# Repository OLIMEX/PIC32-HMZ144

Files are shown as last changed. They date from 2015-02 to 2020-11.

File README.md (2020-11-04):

# PIC32-HMZ144 development board

Product web-page:

https://www.olimex.com/Products/PIC/Development/PIC32-HMZ144/open-source-hardware

Latest revision features:

* Completely OSHW (Open-Source HardWare)
* PIC32MZ2048EFM144 512KB RAM 2MB Flash (other versions of the chip were used for older revisions)
* USB-OTG connector
* MicroSD card connector
* Standard ICSP for debugging and programming
* JTAG pins exposed on 0.1" step 6 pins
* EXT1 and EXT2 50 pin 0.1" connectors for all PIC ports
* RESET and USER buttons
* PWR and STATUS LEDs
* LiPo battery charger and connector
* UEXT connector
* Dimensions: 77 x 52 mm

Demo-software can be found in the software section of the board's web-page. 

Hardware revsion note:

A small number of initially distributed boards might beed a hardware patch for better operation. If your board is revision B and has Q1 with value of 24MHz make sure to apply all of the revision C changes listed below (1, 2, and 3) manually. These hardware changes are required ONLY for boards with printed board revision B and crystal Q1=24Mhz. If your board has a printed revision C or newer, or if Q1=12MHz no hardware changes are required!  

Hardware revisions:

* Revision B patch and revision C notes:

1. The crystal Q1 was changed from 24MHz to Q12.000MHz/HC-49S/SMD/20pF/30ppm;
2. Crystal capacitors (C29, C32) were changed from 27pF to 20pF as required in the errata: "C2=Cload, C1=Cload-2pF" and to have some pF spare, because during production, the capacitance is increased due to flux or dirt;
3. R36=10k pull-up to 3.3V was added to the OSCO pin, i.e. MCU pin<72>.

* Revision C1:

  This is the patched version of PIC32-HMZ144_Rev_C with soldered PIC32MZ2048EFG144-I/PH processors instead of PIC32MZ2048ECG144-I/PH

1. The main processor was changed from PIC32MZ2048ECG144-I/PH to PIC32MZ2048EFG144-I/PH (the ECG was declared "not recommended for new designs" by Microchip)
2. R36 was changed from 10k to 1.5k;
3. Removed quartz Q1. Q1, C29, C32 and R30 were changed to NA - this is because of the errata sheets of both chips. Refer to 4;
4. Added oscillator CD1 instead. CD1 is 24MHz oscillator;
5. Q2, C30 and C31 were changed to NA.

* Revision C2:

  Only difference compared to C1 is a typo in the schematic values, R36 should be marked as 150 Ohm resistor. 
  
  No boards with R36 = 1.5k were ever produced.

* Revision D:

1. The PIC was changed from PIC32MZ2048ECG144T-I/PH to PIC32MZ2048EFM144T-I/PH 
2. According to the PIC32MZ2048 errata sheets:

- Primary oscillator crystal, revision A3 silicon: the primary oscillator has been tested in a normal power-up sequence and supports specific crystal operation.
- The secondary oscillator (SOSC) does not support crystal operation.

Because of this we have added 2 oscillators and have changed the 2 crystals with all corresponding components to NA.

3. One resistor added in series to the 24MHz's crystal. Check the errata sheet for PIC32MZ2048EFM144-I/PH silicon revision A3.
4. PWR_LED and LED1 packages changed.
5. The open source hardware logo was added to the bottom silkscreen.
6. U4 changed from SY8009AAAC(SOT23-5) to SY8089AAAC(SOT23-5).
7. L3 changed from CL470nH/0805/1.76R/250mA to FB0805/600R/2A.
8. FET1 changed from IRLML6402 to WPM2015-3/TR(SOT23-3).
9. Few spacing improvements:
	9.1. The USB-OTG's connector moved 1.00mm towards the middle of the board;
	9.2. The MICRO-SD card's package changed from TFC-WPAPR-08 to TFC-9P-1.5H(ATFFS150A01BR016);
10. UEXT's and Q2's packages improved.

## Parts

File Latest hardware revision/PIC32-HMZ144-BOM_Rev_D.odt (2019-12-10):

PIC32-HMZ144_Rev_D

18.11.2019

Qty Value Device Parts

2 0R(Board_Mounted) R0603 R10, R12

1 0R/R0603 R0603 R37

1 1.1k/1% R0603 R33

1 1M/1% R0603 R9

1 1N5819(S4SOD-123) SOD-123 D1

2 1N5819(SS14) SS14 D2, D3

3 1k R0603 R3, R22, R27

2 2.2k R0603 R13, R15

1 2.2uH/1.5A/DCR<0.1R/CD32 CD32 L4

1 3M R0603 R8

1 4.99k/1% R0603 R32

4 10k R0603 R4, R21, R24, R25

2 10nF C0603 C8, C15

5 10uF/6.3V C0603 C7, C13, C16, C17, C25

1 13k/1% R0603 R6

1 15k R0603 R11

9 22uF/6.3V C0603 C1, C2, C3, C4, C6, C12, C14, C33, C34

2 20pF C0603 C29, C32

1 27pF C0603 C37

3 47k R0603 R2, R14, R16

3 100k R0603 R5, R7, R23

16 100nF C0603 C5, C9, C10, C11, C18, C19, C20, C21, C22, C23, C24, C26, C27, C28, C35, C38

4 330R R0603 R1, R26, R28, R29

1 DW02R DW02R 3.7V-LI_BAT

4 FB0805/600R/2A L0805 FB1, L1, L2, L3

1 GBH-254-SMT-10 GBH-254-SMT-10 UEXT

1 32.768KHZ/20ppm/3.3V/3.20X2.50X1.00MM KK3270046 CD2

1 LED/GREEN/0603 LED-0603 LED1

1 LED/RED/0603 LED-0603 PWR_LED

1 MCP73812T-420I/OT SOT-23-5 U2

2 NA FE25-2FEMALE EXT1, EXT2

7 NA R0603 R17, R18, R19, R20, R31, R34, R35

1 NA(F535L-24(24MHz/50ppm/3.3V/5.00x3.20mm)) 5032_4P CD1

1 NA(1M/1%) R0603 R30

1 NA(10k) R0603 R36

2 NA(10pF) C0603 C30, C31

1 NA(100nF) C0603 C36, C39

1 NA(AP431SA) SOT23 SR1

1 NA(HN1X6) HN1X6 JTAG

1 NA(MC-306_32.768KHz/6pF) MC-306 Q2

1 Q24MHz/HC-49S/SMD/20pF/20ppm HC-49S Q1

1 PIC32MZ2048EFG144-I/PH PIC32MZ2048ECG144-I/PH U1

1 RA1206_(4X0603)-100k R_MATRIX_4E RM1

1 SY6280 SY6280 U3

1 SY8089AAAC(SOT23-5) SY8008 U4

2 T1107A(6X3,8X2,5MM) 6X3,8X2,5MM BUT, RST

1 TESTPAD3 TESTPAD3 GND_PIN

1 TFC-9P-1.7H(ATFFS150A01BR016) TFC-9P-1.7H MICRO-SD

1 USB-OTG MINI_USB9 USB

1 WF6S WF6S ICSP

1 WPM2015-3/TR(SOT23-3) SOT23-3 FET1

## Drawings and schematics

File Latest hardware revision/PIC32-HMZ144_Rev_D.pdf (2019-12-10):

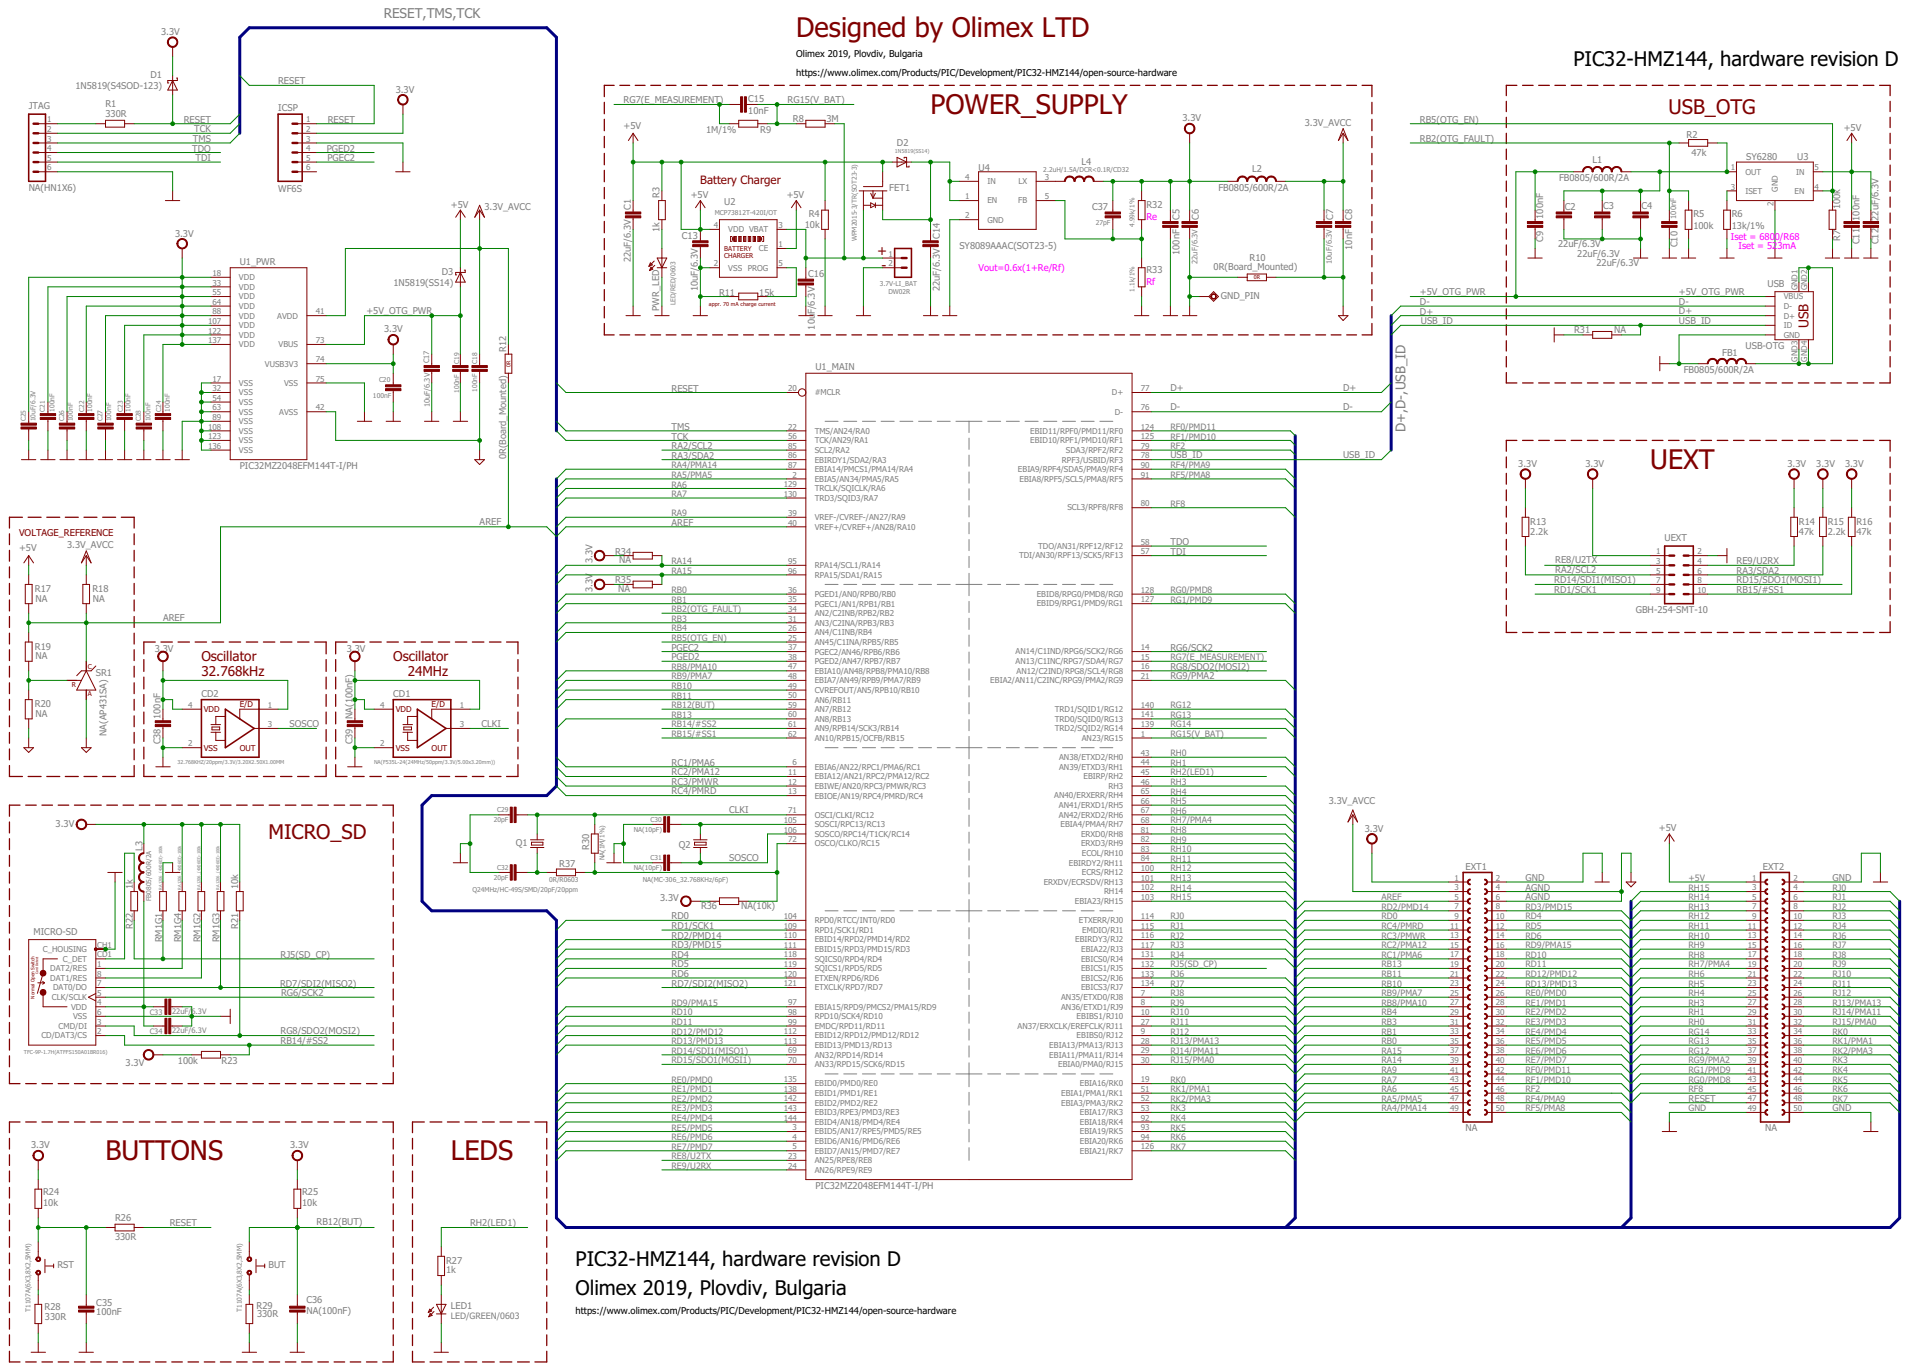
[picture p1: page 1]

Designed by Olimex LTD

https://www.olimex.com/Products/PIC/Development/PIC32-HMZ144/open-source-hardware

3 TMS | 3
TDO 4 | PGED2 4
5 TDI | 5 PGEC2

Iset = 523mA ReRf Vout=0.6x(1+Re/Rf)

appr. 70 mA charge current

122
137

17 | | 73 VUSB3V3

6 AGND | 5
10 | 9 | 10
12 | 11 | 12

22 | RH6 21 | RK0 RJ15/PMA0 RJ15/PMA0 RJ14/PMA11 RJ14/PMA11 RJ13/PMA13 RJ13/PMA13 RJ12 RJ12 RJ11 RJ11 RJ10 RJ10 RJ9 RJ9 RJ8 RJ8 RJ7 RJ7 RJ6 RJ6 RJ4 RJ4 22

RF1/PMD10 | RG0/PMD8 43 | RK4 RK3 44
RF2 | RF8 45 | RK5 RK4 46

RF4/PMA9 | RESET 47 | 48
RF5/PMA8 | GND 49 | 50 GND

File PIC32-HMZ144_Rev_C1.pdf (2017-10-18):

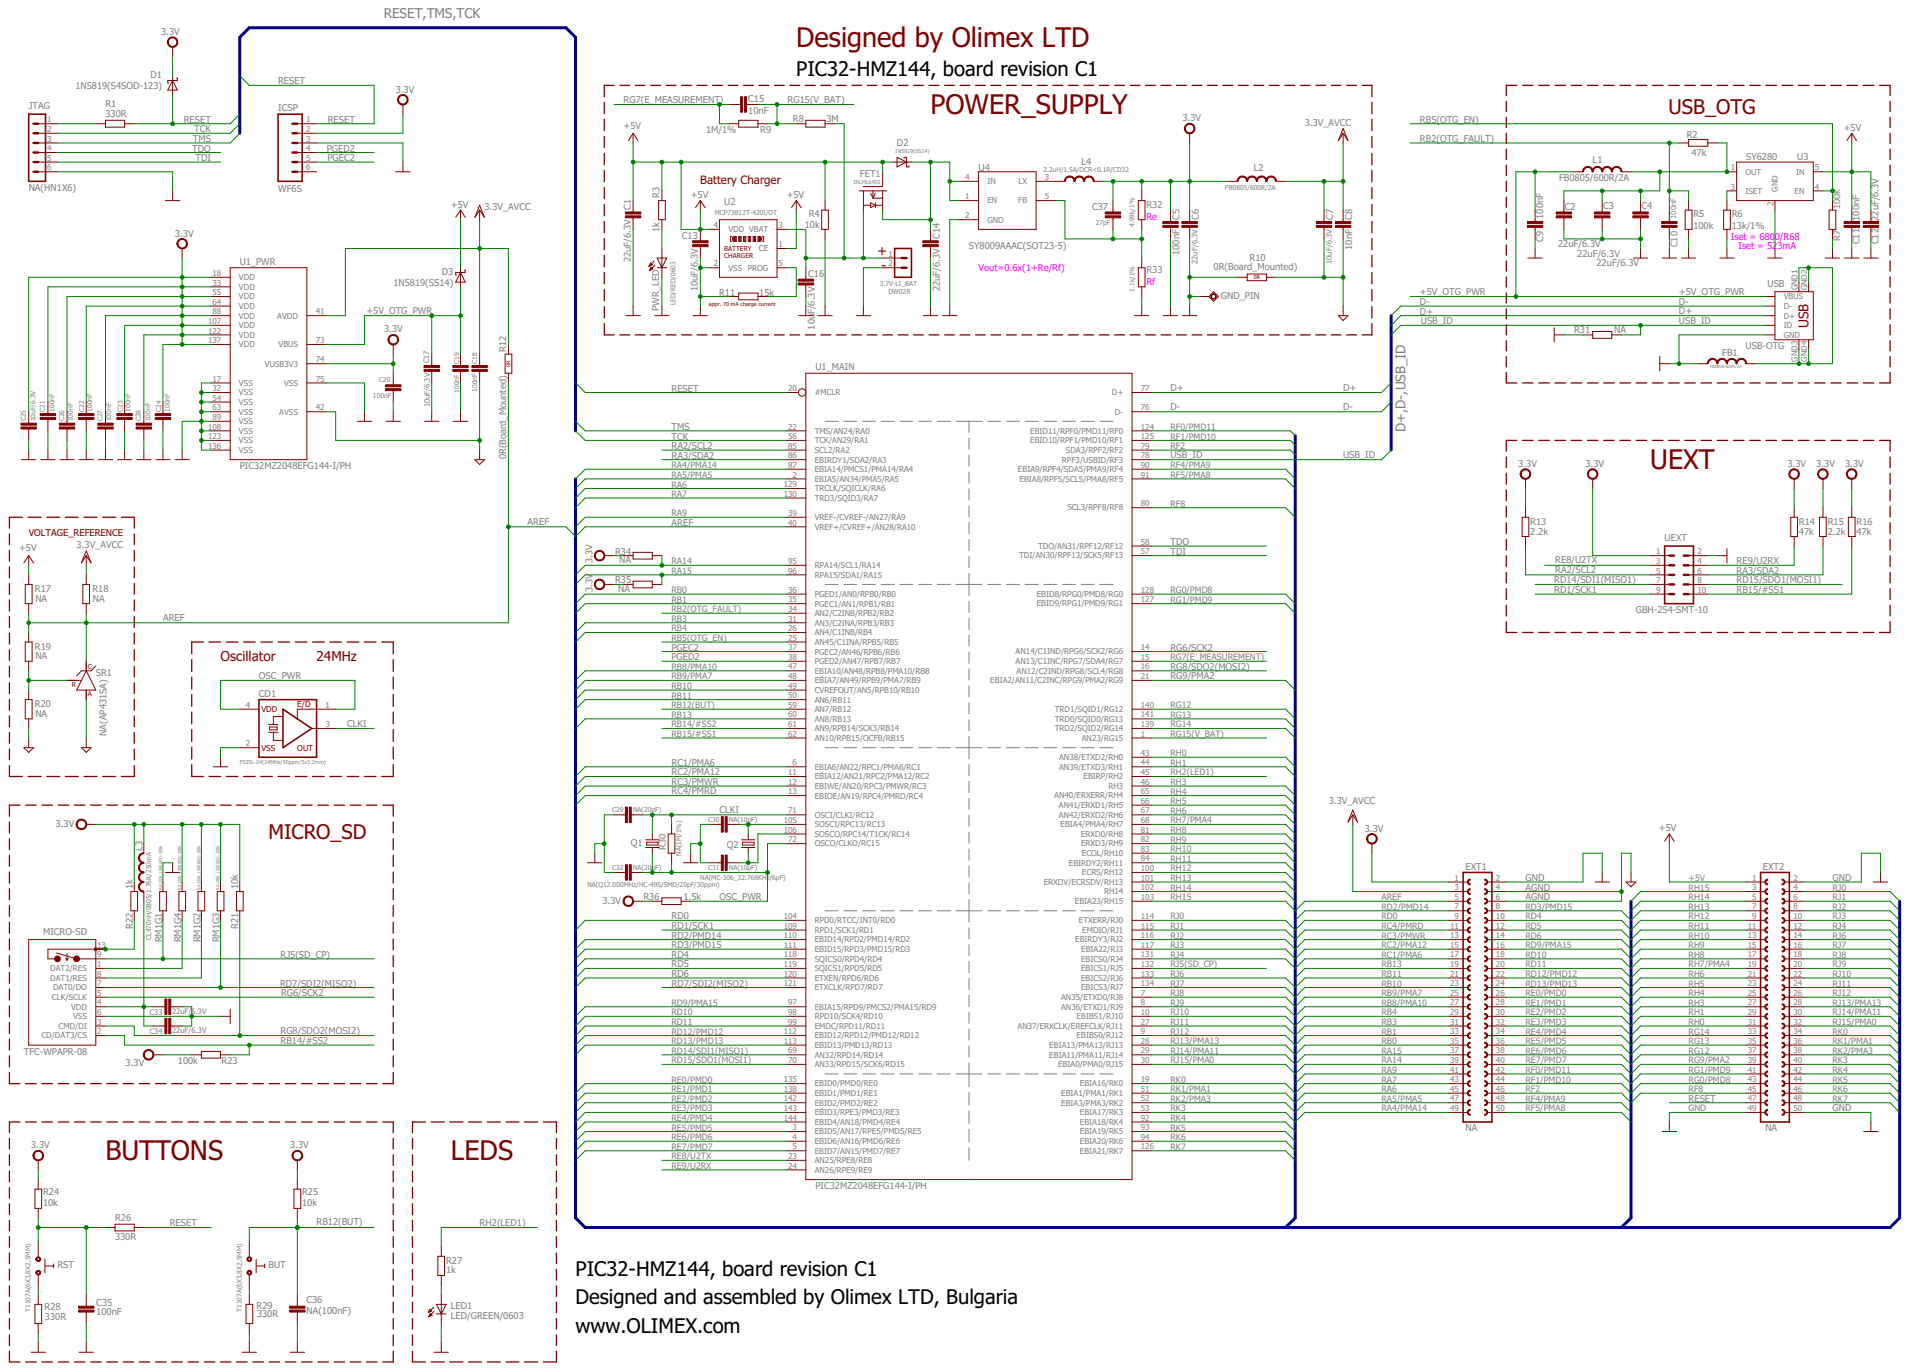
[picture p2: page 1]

Designed by Olimex LTD

3 TMS | 3
TDO 4 | PGED2 4
5 TDI | 5 PGEC2

Iset = 523mA ReRf Vout=0.6x(1+Re/Rf)

appr. 70 mA charge current

10 | 9 | 10
12 | 11 | 12

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

RF4/PMA9 | RESET 47 | 48
RF5/PMA8 | GND 49 | 50 GND

PIC32-HMZ144, board revision C1
Designed and assembled by Olimex LTD, Bulgaria
www.OLIMEX.com

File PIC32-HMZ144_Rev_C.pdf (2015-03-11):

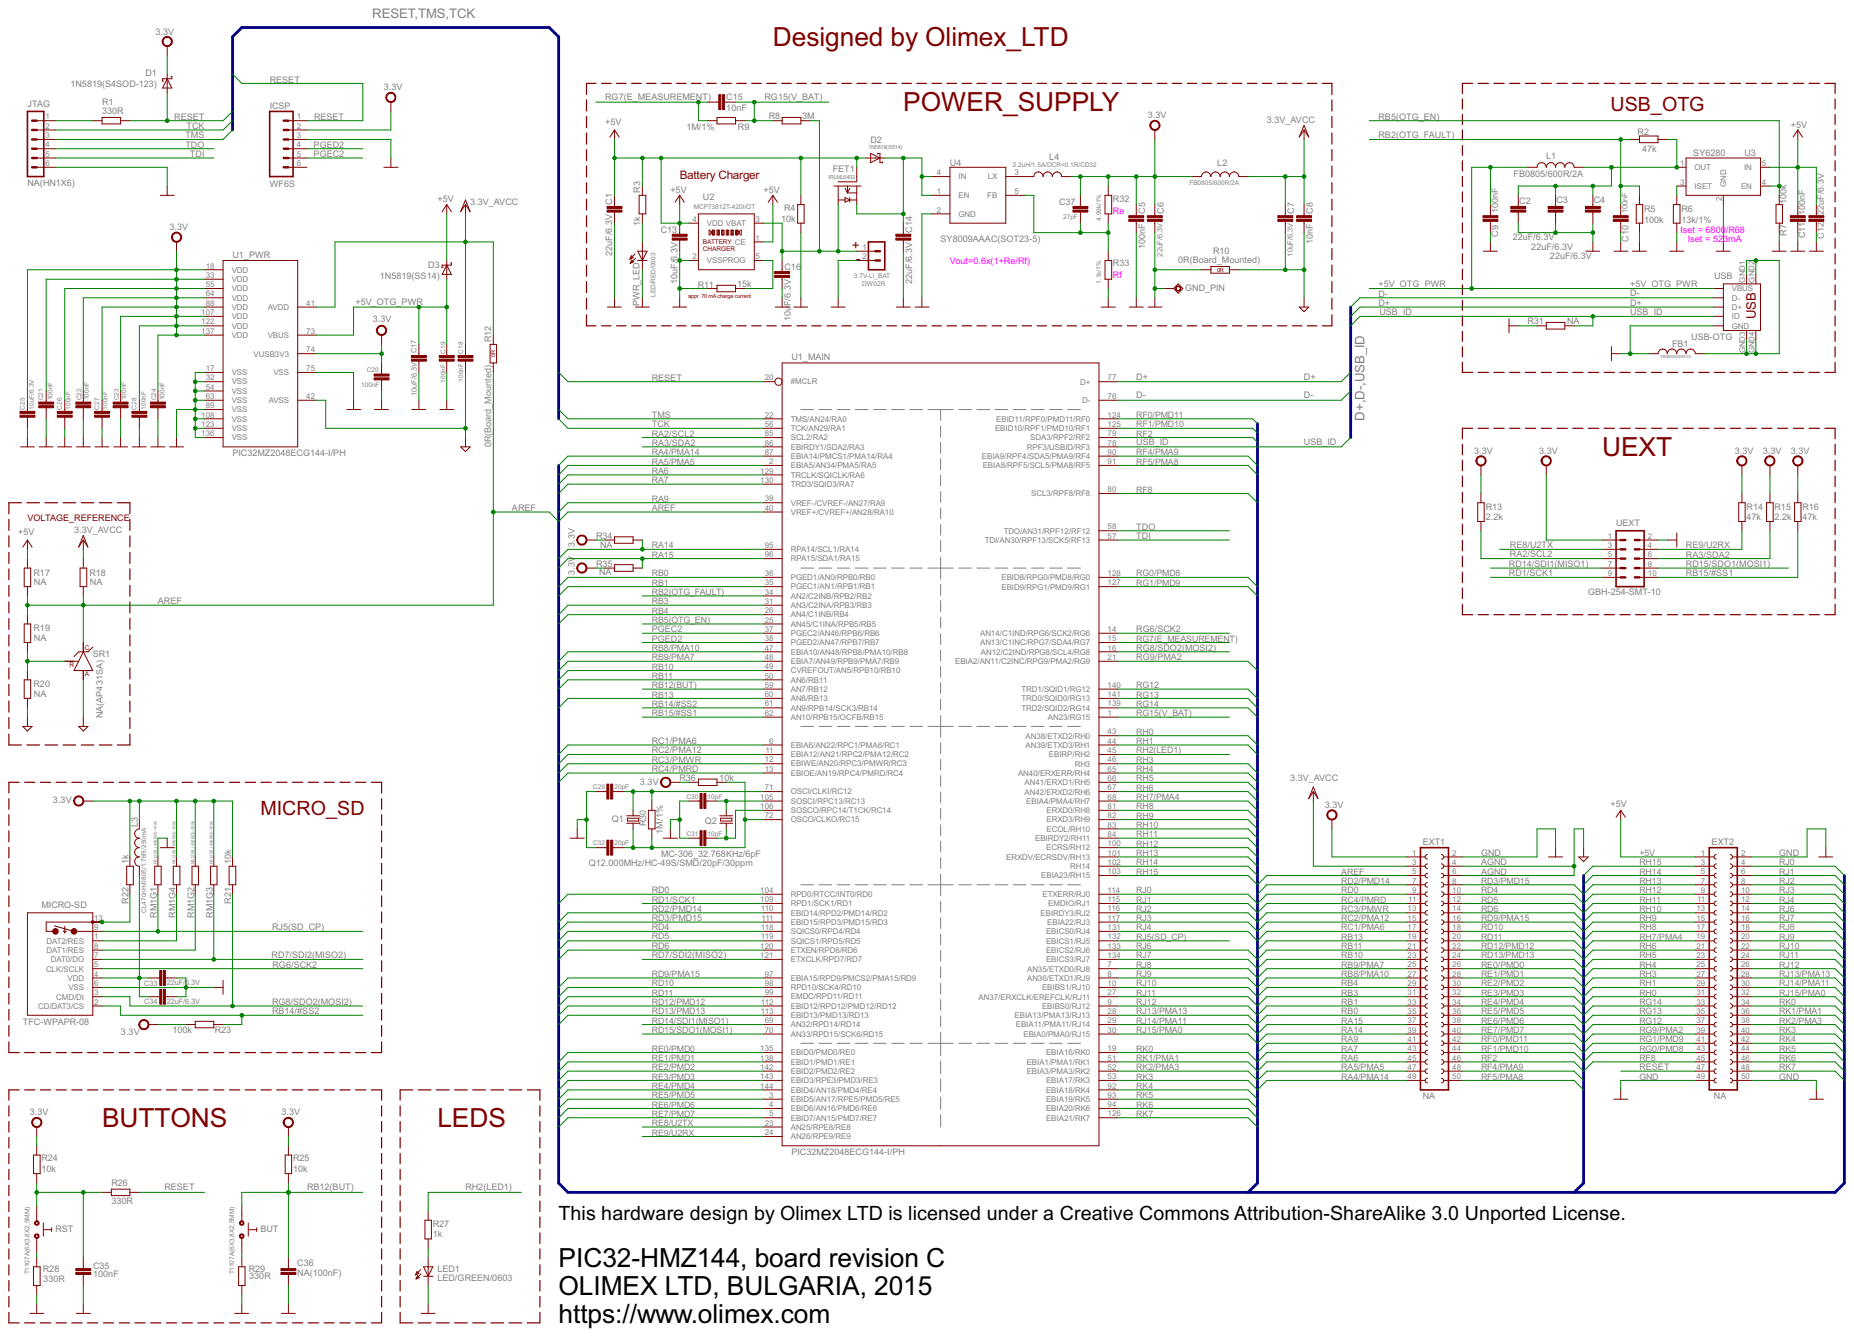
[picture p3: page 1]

4 TDO | 4 PGED2
5 TDI | 5 PGEC2

Iset = 523mA ReRf Vout=0.6x(1+Re/Rf)

appr. 70 mA charge current

137 17 | 73 VUSB3V3

3 AREF 5 | 4 AGND | 3

RD1/SCK1 | | RC4/PMRD 11 | 12 | 11 | 12

111 | | RC3/PMWR 13 RC2/PMA12 15 | 14 16 | RH5 RH10 13 RH9 15 | RJ3 RJ3 14 16

9 | 10 | 9 | 10

RB4 29 | 30 RE2/PMD2 | RH1 29 | 30

RA15 37 | 38 RE6/PMD6 | RG12 37 | 38

RE1/PMD1 138 | | RA6 45 | RF2 46 | RF8 45 | 46
RE2/PMD2 RE3/PMD3 | | RA5/PMA5 47 RA4/PMA14 49 | 48 RF4/PMA9 50 RF5/PMA8 | RESET 47 GND 49 | 48 50 GND

RA7 43 | 44 RF1/PMD10 | RG0/PMD8 43 | 44

RE5/PMD5 | NA | NA

This hardware design by Olimex LTD is licensed under a Creative Commons Attribution-ShareAlike 3.0 Unported License.
PIC32-HMZ144, board revision C
OLIMEX LTD, BULGARIA, 2015
https://www.olimex.com

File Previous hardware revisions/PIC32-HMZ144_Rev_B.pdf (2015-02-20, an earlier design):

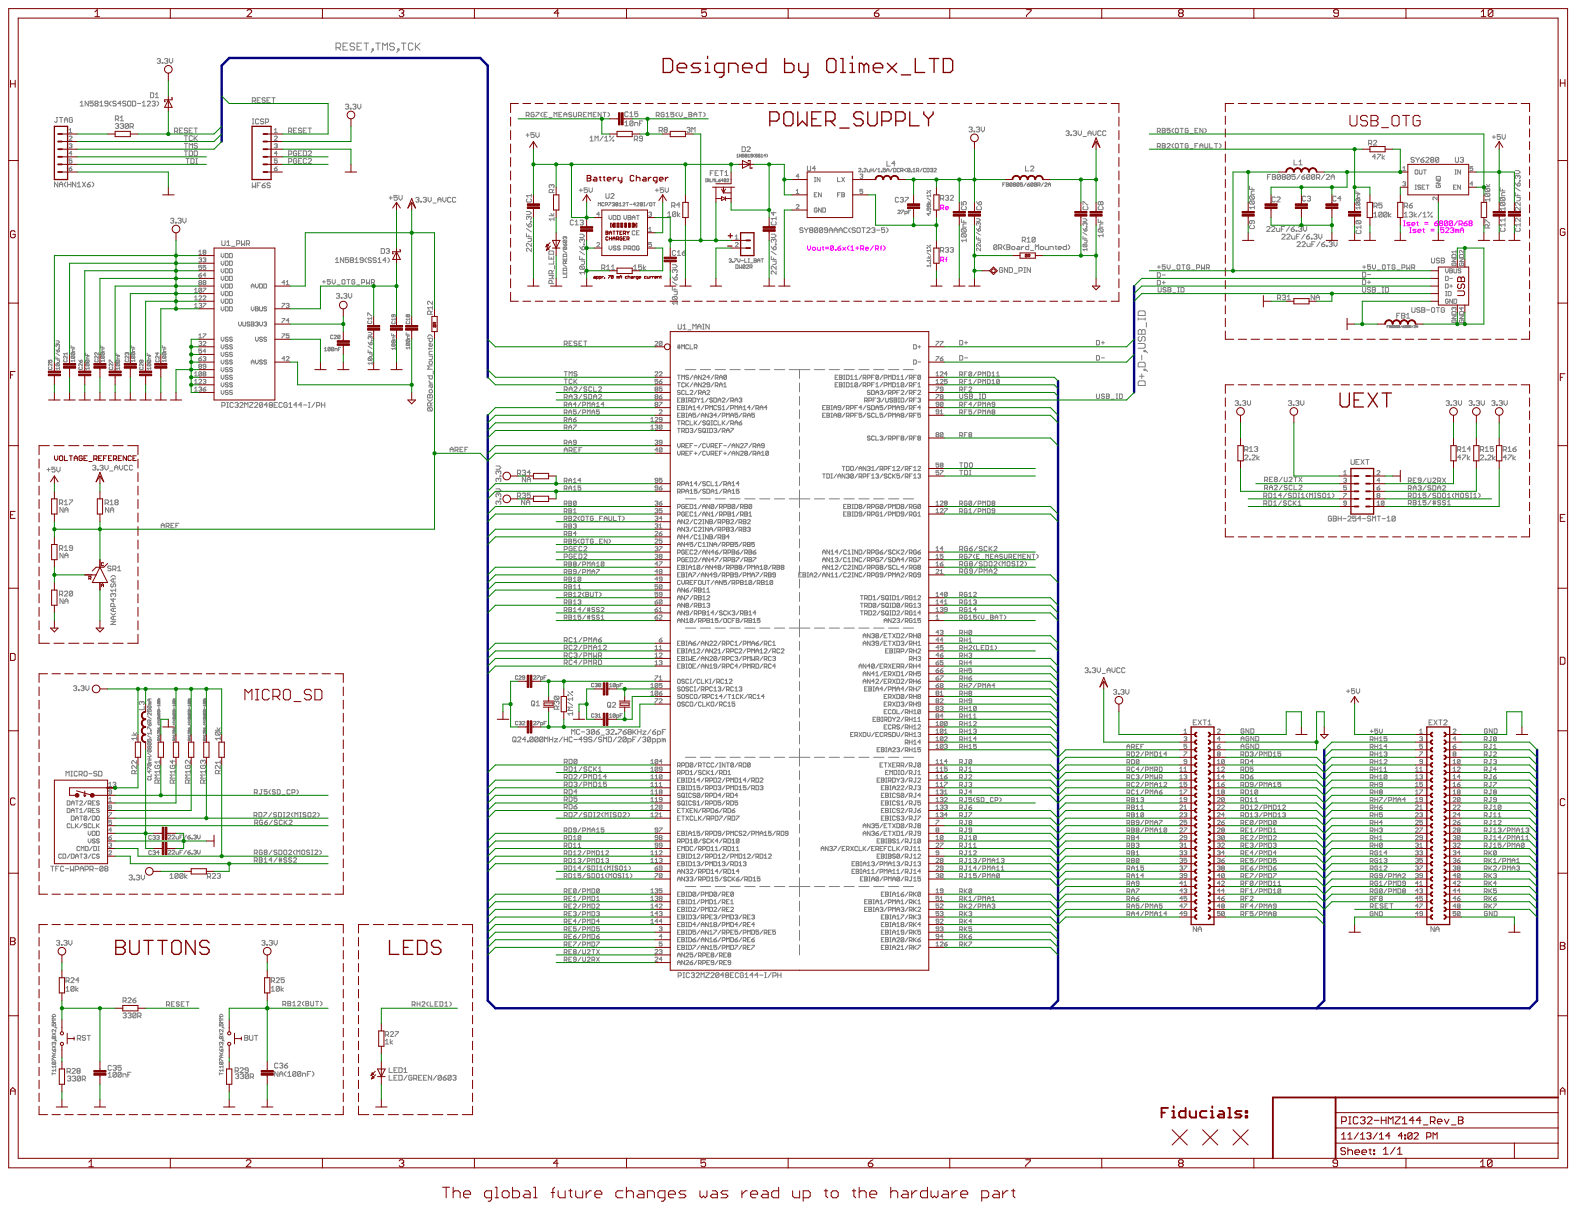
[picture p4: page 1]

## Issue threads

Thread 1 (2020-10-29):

Eagle errors!

T-Skov, 2020-10-29:
I have a little experience with Kicad, but none with Eagle, ver. 9.5.2.free, but  46 errors?

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

DanKoloff, 2020-10-29:
This is a text we have placed. It is not generated from the Eagle. 46 DRC check errors (44 top layer and 2 bottom layer) are expected and manually confirmed to NOT be actual errors. We place this list in case you receive more or less when you run DRC. This means your DRC rules are not properly set.

These are limitations of the Eagle software version 4.16r2 that we used for design back then. Nothing can be done better.

Eagle software version 4.16r2 has global design rules for the board design - and the DRC clearance for the main processor and the rest of the board is different! You can lower the value of the clearance check to less and there would be less errors - however this is a recommended clearance only around the main processor - for the rest of the board the engineers here try to use no less than 5.0 mils between wires (and thus clearance) in order to avoid PCB manufacturing problems! So yes lower the clearance and there would be less errors, but the check might lose consistency and validity and ultimately - its purpose.

Closed 2020-10-29.

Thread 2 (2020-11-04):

Processor name confusion

git-aniket, 2020-11-04:
Hi,

The readme in the repo mentions that the current version has a PIC32MZ2048EFG144 processor, but the product page and users manial mentions PIC32MZ2048EFM144 as the processor:
https://www.olimex.com/Products/PIC/Development/PIC32-HMZ144/open-source-hardware

Could you let us know the exact processor in this board.

DanKoloff, 2020-11-04:
Currently and since last year we've been placing the EFM version - PIC32MZ2048EFM144T-I/PH.

git-aniket, 2020-11-04:
Thanks

Closed 2020-11-04.

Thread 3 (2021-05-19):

Mistake in PIC32-HMZ144 USER ’ S MANUAL

git-aniket, 2021-05-19:
There is a mistake in page 19 of 27 in the data sheet section 6.2.

Datasheet states status LED(green) is connected to pin45(EBIRP/RG2), but actually its connected to RH2.
This can be observed from the schematic on page 10 of the same document.

Datasheet needs updating.

DanKoloff, 2021-05-19:
The latest datasheet seems correct, refer to the  attached picture:

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

git-aniket, 2021-05-19:
Yes! Thanks for letting us know.

Closed 2021-05-19.

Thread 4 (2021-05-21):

Regarding layout of peripherals available on pins

git-aniket, 2021-05-21:
Hi,

Is there a layout, say a pdf or image file somewhere detailing the peripherals available on each of the respective pins?
Something like the below-mentioned picture for the Arduino UNO?
The datasheet for HMZ144 on page 8 shows the Pinout but doesn't show the peripherals available.

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

DanKoloff, 2021-05-21:
Nope we don't have such picture. You can easily connect the picture from the manual with all the perihperals availalbe looking also at the chip's datasheet:

https://ww1.microchip.com/downloads/en/DeviceDoc/PIC32MZ%20EF%20Family%20Datasheet_DS60001320G.pdf

Refer to the table on pages 11 and 12 ("PIN NAMES FOR 144-PIN TQFP DEVICES").

Closed 2021-05-21.

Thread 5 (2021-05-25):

Mounting hole point distances?

git-aniket, 2021-05-25:
Hello,
page 11 of 27 of the manual mentions the physical dimensions of the board.
However, the mounting hole distances are missing from the schematic.
Using the provided info I couldn't calculate the exact values either.

Would it be possible to provide the exact mounting hole distances for the board?

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

DanKoloff, 2021-06-01:
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

It is OSHW board and the design files are available if you find older version of Eagle you can measure anything with the ruler tool.

git-aniket, 2021-06-01:
Thank You Dan.

Closed 2021-06-01.

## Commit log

2015-02-20 PIC32-HMZ144 CAD files upload
    [PIC32-HMZ144_Rev_B.brd, PIC32-HMZ144_Rev_B.sch]
2015-03-11 Revsion C board changes
    [PIC32-HMZ144_Rev_C.brd, PIC32-HMZ144_Rev_C.sch]
2017-10-18 update
    new revision with EFG144 (instead of the not-recommended ECG144)
    [PIC32-HMZ144_Rev_C1.brd, PIC32-HMZ144_Rev_C1.sch]
2019-05-08 update
    r36=150ohm
    [PIC32-HMZ144_Rev_C2.brd, PIC32-HMZ144_Rev_C2.sch]
2019-12-10 update
    update revision D
    [PIC32-HMZ144_Rev_B.brd, PIC32-HMZ144_Rev_B.sch, PIC32-HMZ144_Rev_C.brd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]
